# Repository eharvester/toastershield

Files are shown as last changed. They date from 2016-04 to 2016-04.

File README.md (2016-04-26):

# **toastershield**

An SMT reflow oven shield for the Arduino Uno.

## 1. Software
 
 The following steps were tested in Linux (Ubuntu).
 
### Set the following environment variables

`PATH_TO_ARDUINO_IDE = /path/to/your/arduinoIDE`

`ARDUINO_IDE_VER = 1.6.X`  (depending on your version)

`GITHUB_MIRROR = /path/to/your/github/mirror` (optional, local github mirror otherwise https://github.com is used per default)

### Connect Arduino Uno via USB cable

Make sure you have write permissions to `/dev/ttyUSB0` and execute the following commands:

`$make`

`$make upload`

If the shield is attached to the Arduino Uno board, you should hear a beep  and see something on the display.

## 2. Hardware

**_WARNING - DANGER - HIGH VOLTAGE - ELECTRIC SHOCK HAZARD - EXPERTS ONLY
(shield, heater, fan and transformer are connected to 120VAC)_**

### Parts List:

- toaster oven, to be converted (for use on 120VAC)
- Arduino Uno board
- toastershield PCB (see Eagle files and parts list)
- transformer PCB (see Eagle files and parts list)
- SH1106 OLED module
- 2 pushbuttons
- 1 LED,
- 2 wafer connectors (4 pin)
- some ribbon cable (to connect the OLED module and the switches+LED with wafer connectors)
- power cable with ground / 20 A
- power cable feedthrough coupler
- K-type thermocouple wire pair (about 50cm)
- some cable (AWG 16 for heater, AWG 24 for fan and 12VAC supply)
- 6.3mm crimp terminal spade connectors (female, insulated)
- ring tongue crimp terminals (for grounding)
- hardware for mounting boards and grounding
- fiberglass cloth (for thermal insulation)
- silicone glue

PCBs can be made with the [toner transfer method](http://www.instructables.com/id/Cheap-and-Easy-Toner-Transfer-for-PCB-Making) easily (single layer). All goes inside the oven (original buttons, switches, timers, bell aso. are stripped out). Make sure that there is sufficient air ventilation in order to keep the temperature around the boards and cables below 70C (a cooling fan might be necessary). Some thermal insulation on the outside of the oven compartment is necessary (treat fiberglass cloth with silicon glue on the cutting lines before cutting). Cut out an opening for the USB port, preferably on the front (so you can easily update the firmware and optionally monitor and control the oven from a computer).  Drill a hole into the oven compartment wall and feed the thermocouple wire pair through it and seal the hole with silicone glue later (after everything is working and tested). 

**_WARNING - DANGER - HIGH VOLTAGE - ELECTRIC SHOCK HAZARD - EXPERTS ONLY
(shield, heater, fan and transformer are connected to 120VAC)_**

## 3. To Do
- menu for adjusting temperature/time (at the moment fixed for PbSn solder) via pushbuttons
- interface for Processing
- Processing GUI  

***
## Pictures:
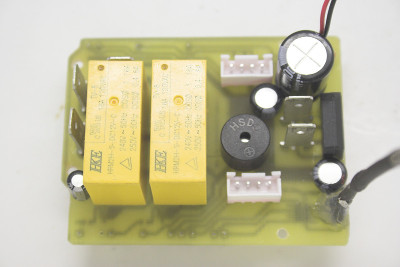
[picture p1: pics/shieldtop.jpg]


Picture 1: Assembled shield top.
***

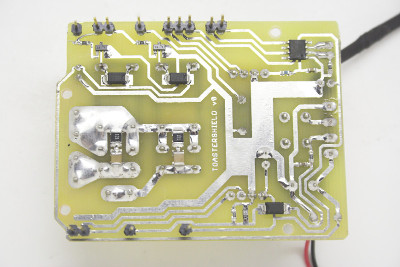
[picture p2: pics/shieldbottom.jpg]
 

Picture 2: Assembled shield bottom.
***

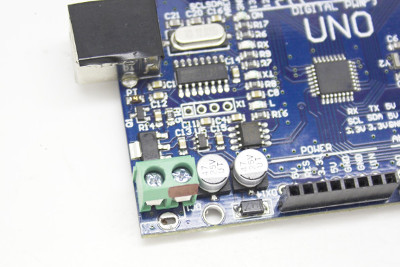
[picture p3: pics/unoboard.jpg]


Picture 3: Modified power connection, plug replaced by screw terminals.
***

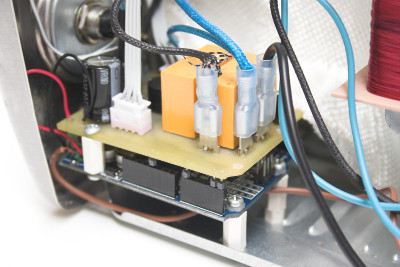
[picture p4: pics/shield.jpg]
  

Picture 4: Wired shield sitting on Uno board.
***

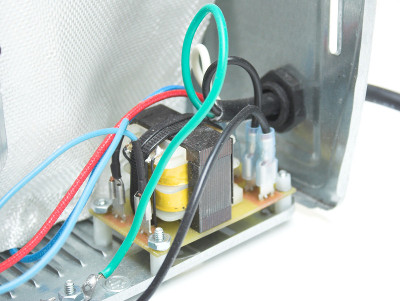
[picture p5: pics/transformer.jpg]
 

Picture 5: Wired transformer board.
***

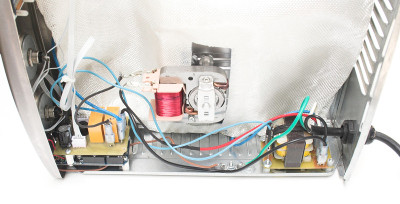
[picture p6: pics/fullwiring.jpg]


Picture 6: Complete wiring.
***
 
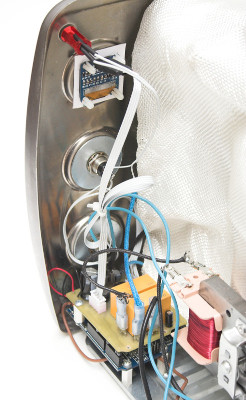
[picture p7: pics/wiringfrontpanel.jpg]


Picture 7: Wiring of front panel.
***

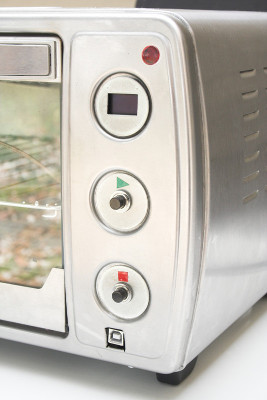
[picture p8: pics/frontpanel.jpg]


Pincture 8: Front panel.

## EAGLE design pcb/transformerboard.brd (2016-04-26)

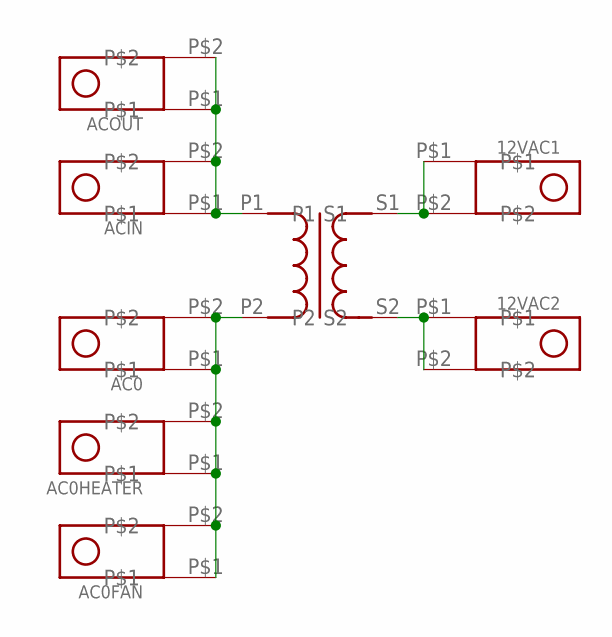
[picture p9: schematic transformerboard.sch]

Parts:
12VAC1, 12VAC2: QUICKCONNECT-TAB; QUICKCONNECT-TAB-6.35X0.81
AC0, AC0FAN, AC0HEATER: QUICKCONNECT-TAB; QUICKCONNECT-TAB-6.35X0.81
ACIN: QUICKCONNECT-TAB; QUICKCONNECT-TAB-6.35X0.81
ACOUT: QUICKCONNECT-TAB; QUICKCONNECT-TAB-6.35X0.81
T1: TRANSFORMER; 1.6X1.4.X1.3

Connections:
unnamed: ACIN.P$1, ACIN.P$2, ACOUT.P$1, ACOUT.P$2, T1.P1
unnamed: AC0.P$1, AC0.P$2, AC0FAN.P$1, AC0FAN.P$2, AC0HEATER.P$1, AC0HEATER.P$2, T1.P2
unnamed: 12VAC1.P$1, 12VAC1.P$2, T1.S1
unnamed: 12VAC2.P$1, 12VAC2.P$2, T1.S2

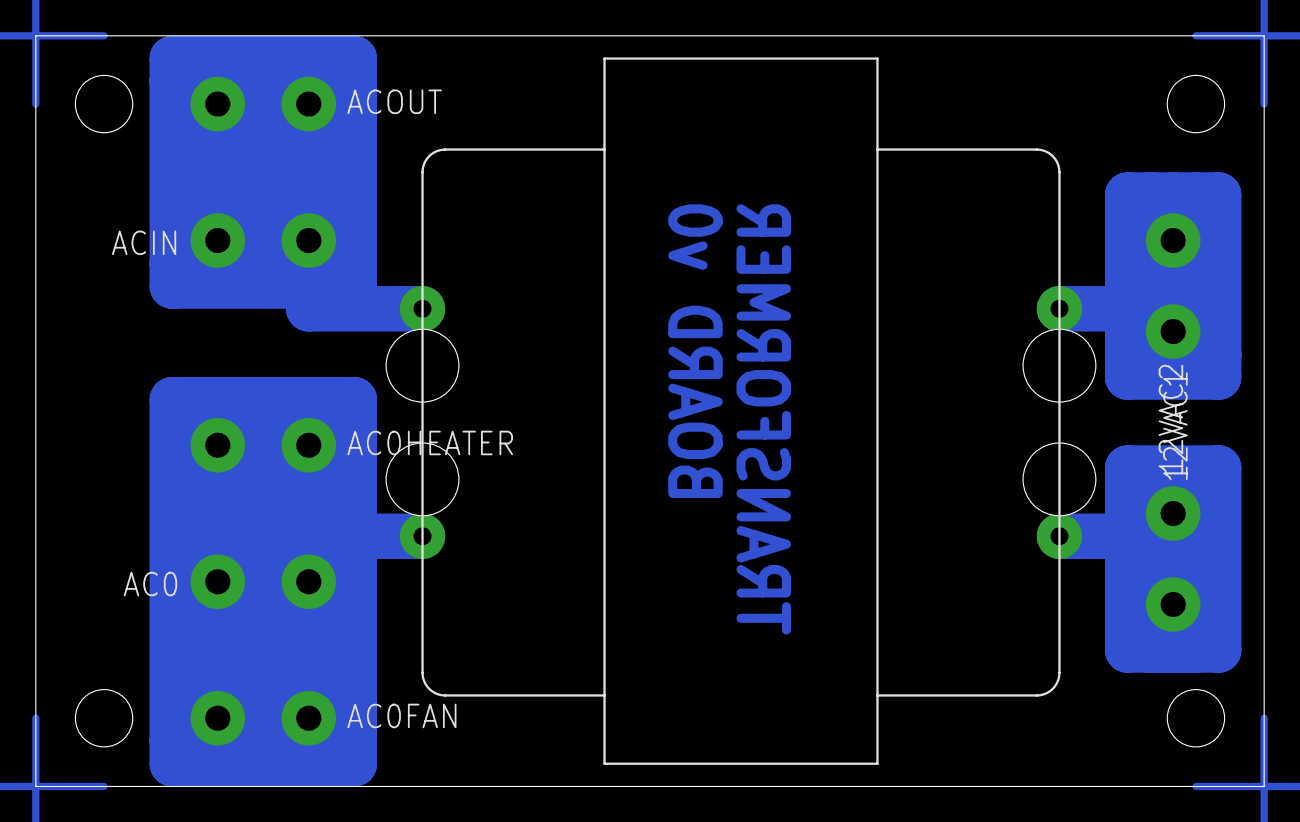
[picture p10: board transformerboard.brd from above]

Board: 2 copper layers, 68.6 x 41.9 mm, 8 parts (0 on the bottom side), 4 nets.

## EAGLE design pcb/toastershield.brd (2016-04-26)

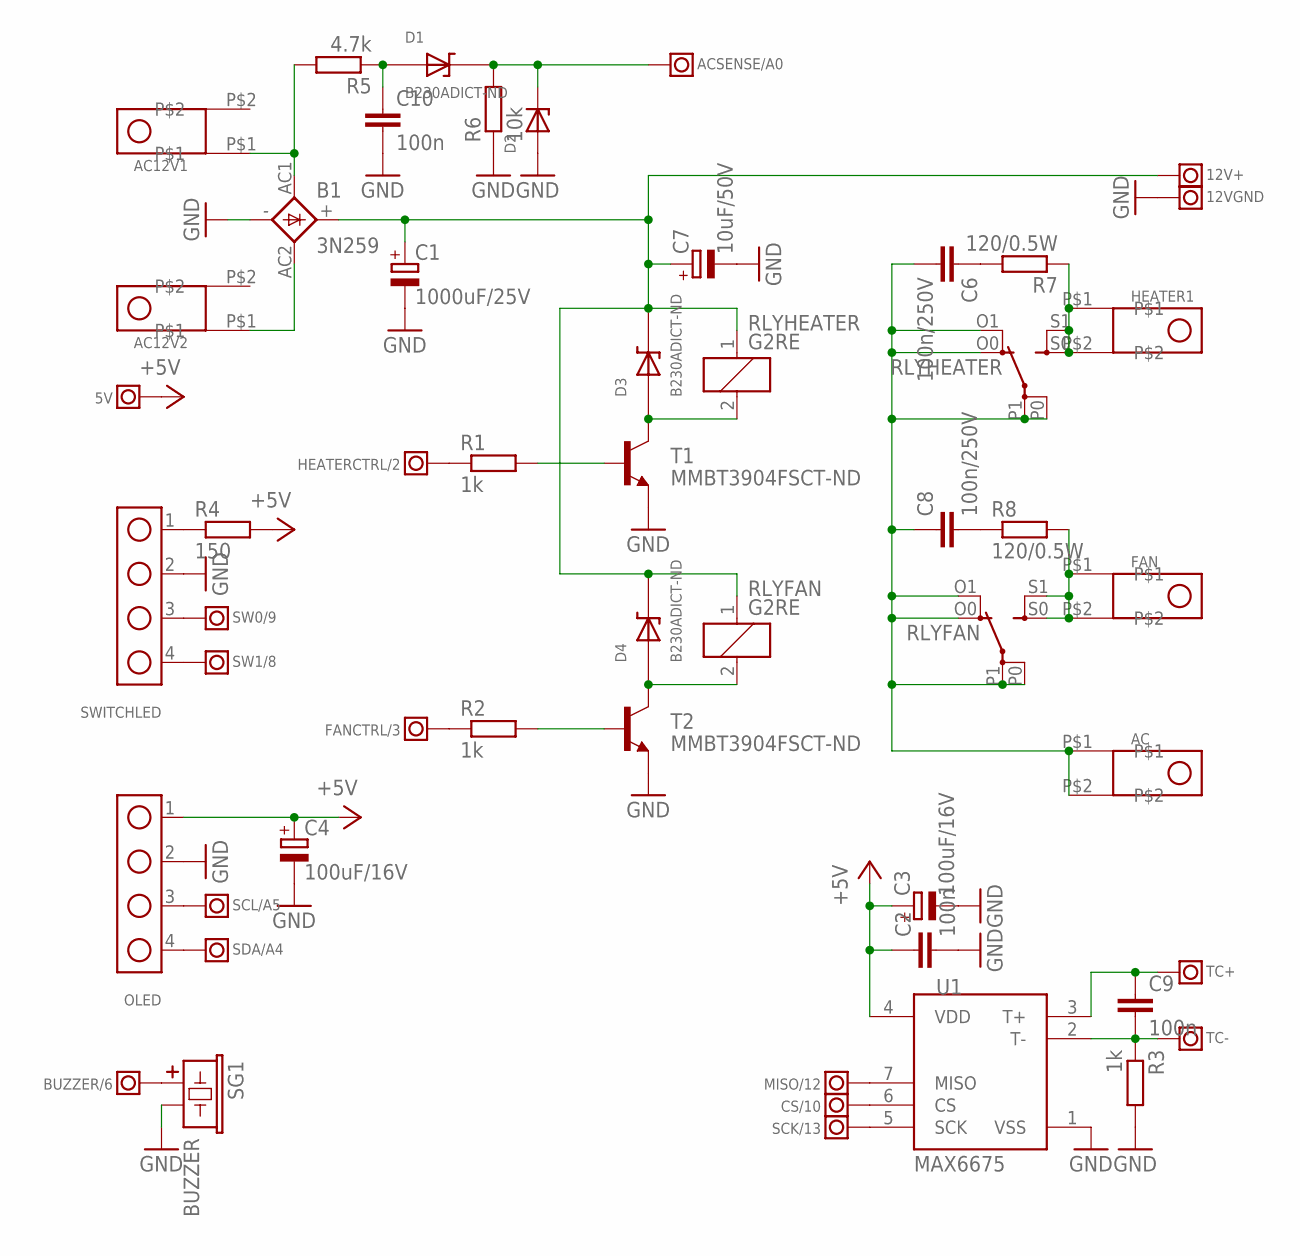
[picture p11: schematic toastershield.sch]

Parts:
5V, 12V+, 12VGND: PIN-HEADER; PIN-HEADER-MALE
AC, AC12V1, AC12V2: QUICKCONNECT-TAB; QUICKCONNECT-TAB-6.35X0.81
ACSENSE/A0: PIN-HEADER; PIN-HEADER-MALE
B1: 3N259; KBPM
BUZZER/6: PIN-HEADER; PIN-HEADER-MALE
C1: 1000uF/25V; E5-13
C2, C9, C10: 100n; C0603
C3, C4: 100uF/16V; E2,5-7
C6, C8: 100n/250V; C1210
C7: 10uF/50V; E2,5-5
CS/10: PIN-HEADER; PIN-HEADER-MALE
D1, D3, D4: B230ADICT-ND; SMA/SMB
D2: MA8051CT; SOD323-W
FAN: QUICKCONNECT-TAB; QUICKCONNECT-TAB-6.35X0.81
FANCTRL/3: PIN-HEADER; PIN-HEADER-MALE
HEATER1: QUICKCONNECT-TAB; QUICKCONNECT-TAB-6.35X0.81
HEATERCTRL/2: PIN-HEADER; PIN-HEADER-MALE
MISO/12: PIN-HEADER; PIN-HEADER-MALE
OLED: 4-PIN-WAFER-CONN; WAFER_MALE_4PIN
R1, R2, R3: 1k; R0603
R4: 150; R0603
R5: 4.7k; R0603
R6: 10k; R0603
R7, R8: 120/0.5W; R1210
RLYFAN: G2RE
RLYHEATER: G2RE
SCK/13: PIN-HEADER; PIN-HEADER-MALE
SCL/A5: PIN-HEADER; PIN-HEADER-MALE
SDA/A4: PIN-HEADER; PIN-HEADER-MALE
SG1: BUZZER; BUZZER-12X7.5
SW0/9, SW1/8: PIN-HEADER; PIN-HEADER-MALE
SWITCHLED: 4-PIN-WAFER-CONN; WAFER_MALE_4PIN
T1, T2: MMBT3904FSCT-ND; SOT-23
TC+: PIN-HEADER; PIN-HEADER-MALE
TC-: PIN-HEADER; PIN-HEADER-MALE
U1: MAX6675; SO08-MAX6675

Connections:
12VDC: 12V+.P$1, B1.+, C1.+, C7.+, D3.1 (CAT), D4.1 (CAT), RLYFAN.1, RLYHEATER.1
+5V: 5V.P$1, C2.1, C3.+, C4.+, OLED.1, R4.2, U1.4 (VDD)
AC: AC.P$1, AC.P$2, C6.2, C8.1, RLYFAN.O0 (O), RLYFAN.O1 (O), RLYFAN.P0, RLYFAN.P1, RLYHEATER.O0 (O), RLYHEATER.O1 (O), RLYHEATER.P0, RLYHEATER.P1
AC12V0: AC12V1.P$1, B1.AC1, R5.2
AC12V1: AC12V2.P$1, B1.AC2
BUZZER: BUZZER/6.P$1, SG1.+ (1)
FAN: FAN.P$1, FAN.P$2, R8.2, RLYFAN.S0 (S), RLYFAN.S1 (S)
GND: 12VGND.P$1, B1.-, C1.-, C2.2, C3.-, C4.-, C7.-, C10.2, D2.A (AN), OLED.2, R3.2, R6.1, SG1.- (2), SWITCHLED.2, T1.2 (E), T2.2 (E), U1.1 (VSS)
HEATER: HEATER1.P$1, HEATER1.P$2, R7.1, RLYHEATER.S0 (S), RLYHEATER.S1 (S)
LED+: R4.1, SWITCHLED.1
unnamed: C9.1, TC+.P$1, U1.3 (T+)
unnamed: FANCTRL/3.P$1, R2.1
unnamed: HEATERCTRL/2.P$1, R1.1
unnamed: D3.2 (AN), RLYHEATER.2, T1.3 (C)
unnamed: D4.2 (AN), RLYFAN.2, T2.3 (C)
unnamed: R1.2, T1.1 (B)
unnamed: R2.2, T2.1 (B)
unnamed: MISO/12.P$1, U1.7 (MISO)
unnamed: C9.2, R3.1, TC-.P$1, U1.2 (T-)
unnamed: CS/10.P$1, U1.6 (CS)
unnamed: SCK/13.P$1, U1.5 (SCK)
unnamed: SW0/9.P$1, SWITCHLED.3
unnamed: SW1/8.P$1, SWITCHLED.4
unnamed: OLED.3, SCL/A5.P$1
unnamed: OLED.4, SDA/A4.P$1
unnamed: C10.1, D1.2 (AN), R5.1
unnamed: ACSENSE/A0.P$1, D1.1 (CAT), D2.C (CAT), R6.2
unnamed: C8.2, R8.1
unnamed: C6.1, R7.2

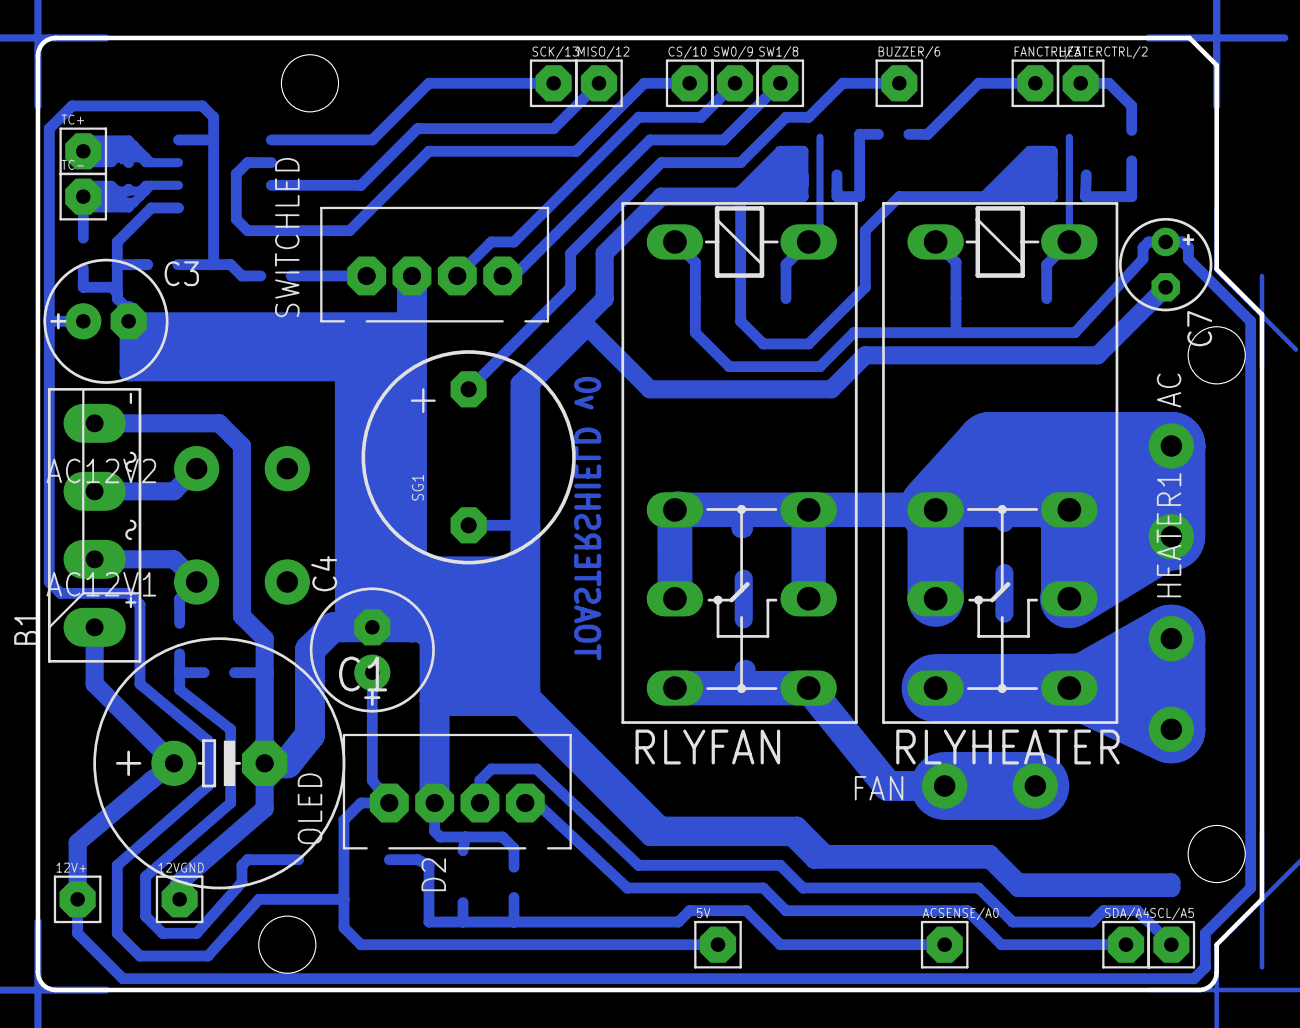
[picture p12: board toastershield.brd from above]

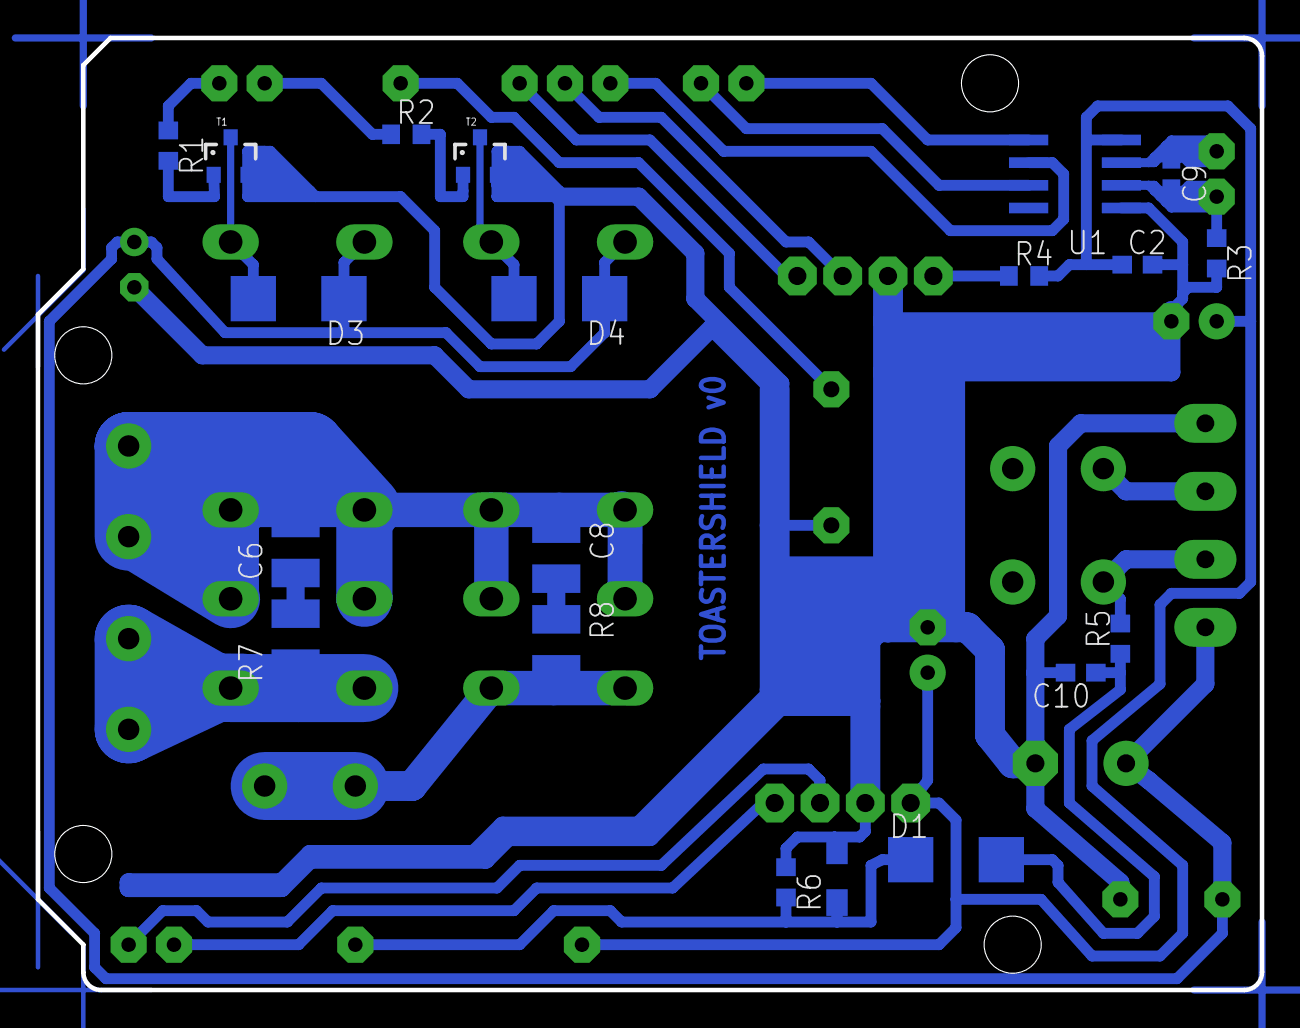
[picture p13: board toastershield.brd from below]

Board: 2 copper layers, 68.6 x 53.3 mm, 51 parts (19 on the bottom side), 29 nets.

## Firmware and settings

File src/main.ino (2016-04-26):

// Toastershield
// a shield for Arduino Uno
// to use a toaster oven as SDM reflow oven

#define Version 0.1

// pin definitions
#define SW0 9
#define SW1 8

#define FANCTRL 3
#define HEATERCTRL 2

#define ACSENSE A0

//MAX6675 SPI pin definitions
#define CSTC  10               //chip select pin for MAX6675

#define SWSTART SW0
#define SWSTOP SW1


// PID controller definitions
#include <PID_v1.h>
double Setpoint, Input, Output;
#include "PIDparams.h"

// PID controller object
PID myPID(&Input, &Output, &Setpoint, Kp, Ki, Kd, DIRECT);

unsigned long windowStartTime;

#define PWM_WINDOWSIZE_MS 5000
#define PID_OUTPUT_MAX 800.0
#define PID_OUTPUT_MIN 0.0

// Thermocouple definitions
#include <xMAX6675.h>      

#define MOSI  11    //master out slave in (not connected, only read MAX6675)
#define MISO  12    //master in slave out
#define SCK   13    //serial clock

// thermocouple object
xMAX6675 tc; 

#define tCONV 220   // conversion time is 0.22s per data sheet
#define nMEAS 8     // number of measurements to average

double TempC[nMEAS], TempCAvg;

unsigned char TempCIdx;
unsigned long TempLastMillis;

unsigned long SoakStart, HeatStart;

#include "reflowdefs.h"

#define HEATRAMP_TIMEOUT 200000UL
#define HEATSOAK_TIMEOUT HEATRAMP_TIMEOUT+200000UL
#define HEATREFLOW_TIMEOUT HEATSOAK_TIMEOUT+200000UL

// LCD definitions
#include <Arduino.h>
#include <Wire.h>
#include <MicroLCD.h>
LCD_SSD1306 lcd; /* for SH1106 OLED module */

#define LCD_SIZEX SSD1306_LCDWIDTH
#define LCD_SIZEY SSD1306_LCDHEIGHT

#include "lcdsymbols.h"

#define READY_TEXT    "  READY   "
#define RAMPUP_TEXT   " HEAT UP  "
#define SOAK_TEXT     "   SOAK   "      
#define REFLOWUP_TEXT "  REFLOW  "
#define OPENDOOR_TEXT "OPEN DOOR!"
#define COOLDOWN_TEXT "COOL DOWN "
#define ERROR_TEXT    "  ERROR   "

#define LCD_YPOS_TEMP 1
#define LCD_YPOS_SYMBOL 1
#define LCD_YPOS_BAR 4
#define LCD_YPOS_STATE 6

// Buzzer
#include "pitches.h"
#define BUZZER 6 // pin

#define TL 50
#define PAUSE 250

// delay for relays to turn them on/off tuned for AC zero crossing 
// these values should be good for the relay model
// they can be optimizied through characterization
// for other models they must be changed through characterization
//  or simpe AC oscilloscope measurement of switched voltage
#define HEATERON_DELAY 9
#define HEATEROFF_DELAY 5
#define FANRON_DELAY 9
#define FANOFF_DELAY 3

#define ACSENSETIMEOUT_MS 17 // avoid blocking, when oven is not powered by AC, but USB

unsigned char AcSense(void) {

 unsigned long Millis;

 Millis = millis();
 while (digitalRead(ACSENSE)) {if (millis() > Millis+ACSENSETIMEOUT_MS) return 0;};

 Millis = millis();
 while (!digitalRead(ACSENSE)) {if (millis() > Millis+ACSENSETIMEOUT_MS) return 0;};

 return 1;
}

#define HEATER_ON {if (AcSense()) { delay(HEATERON_DELAY); digitalWrite(HEATERCTRL,1);} lcd.setCursor(8,LCD_YPOS_SYMBOL); lcd.draw(HeaterSymbol16x16,16,16);} 
#define HEATER_OFF {if (AcSense()) { delay(HEATEROFF_DELAY); digitalWrite(HEATERCTRL,0);} lcd.setCursor(8,LCD_YPOS_SYMBOL); lcd.draw(EmptySymbol16x16,16,16);}

#define IF_HEATER_ON digitalRead(HEATERCTRL)

#define FAN_ON {if (AcSense()) {  delay(FANRON_DELAY); digitalWrite(FANCTRL,1);} lcd.setCursor(104,LCD_YPOS_SYMBOL); lcd.draw(FanSymbol16x16,16,16);} 
#define FAN_OFF  {if (AcSense()) { delay(FANOFF_DELAY); digitalWrite(FANCTRL,0);} lcd.setCursor(104,LCD_YPOS_SYMBOL); lcd.draw(EmptySymbol16x16,16,16);}

#define IF_FAN_ON digitalRead(FANCTRL)

enum ReflowFsmState {READY, STARTPID, RAMPUP, SOAK, REFLOWUP, OPENDOOR, COOLDOWN, ERROR} ReflowFsm;

void alarm() {
 tone(BUZZER, NOTE_B7);
 delay(TL);
 tone(BUZZER, NOTE_D7);
 delay(TL);
 tone(BUZZER, NOTE_F7);
 delay(TL);
 tone(BUZZER, NOTE_D7);
 delay(TL);
 tone(BUZZER, NOTE_B7);
 delay(TL);
   
 noTone(BUZZER);
}

void beep () {
 tone(BUZZER, NOTE_B7);
 delay(TL);
 noTone(BUZZER);
}

void errorbeep () {
 tone(BUZZER, NOTE_F7);
 delay(TL);
 noTone(BUZZER);
}

bool pressed(unsigned char pbswitch) {

 if (!digitalRead(pbswitch)) {
   beep();
   while (!digitalRead(pbswitch));
   return true;
 } else {
   return false;
 }
}

void wrongpressed(unsigned char pbswitch) {

 unsigned int vandalcheck = 0; 

 if (!digitalRead(pbswitch)) {
  errorbeep();
  for (;(vandalcheck < 10000) && !digitalRead(pbswitch); vandalcheck++);
 }

}

// average function
double Avg (double Vals[]) {

 unsigned char n;
 double Sum = 0.0;
// sum values   
 for (n = 0; n < nMEAS; n++) Sum += Vals[n];
 return (Sum/(double)nMEAS);
}

#define IF_STOP {if (pressed(SWSTOP)) ReflowFsm = COOLDOWN;}
#define WRONG_STOP {wrongpressed(SWSTOP); }
#define WRONG_START {wrongpressed(SWSTART); }

void setup() {

 unsigned char n;
 unsigned long Millis;

 Millis = millis();
  
 tc.attach(MOSI,MISO,SCK,CSTC); // attach the thermocouple

// switches pull up
 pinMode(SW0, INPUT_PULLUP);  
 pinMode(SW1, INPUT_PULLUP);  

 pinMode(ACSENSE,INPUT);

// relays
 digitalWrite(FANCTRL,0);
 pinMode(FANCTRL,OUTPUT);

 digitalWrite(HEATERCTRL,0);
 pinMode(HEATERCTRL,OUTPUT);

// buzzer
 pinMode(BUZZER,OUTPUT);

 delay(100);  // otherwise OLED does not start
// LCD
 lcd.begin();
 lcd.clear();
 lcd.setCursor(40, 3);
 lcd.setFontSize(FONT_SIZE_XLARGE);
 lcd.print("V "); lcd.print(Version);
 delay(1000);
 lcd.clear();
 lcd.setCursor(0,0);
 lcd.draw(logo, 128, 64);
 errorbeep();
 delay(100);
 beep();
 delay(500);


// PID controller
 Setpoint = PID_OUTPUT_MIN;
 Output = 0.0; 
 Input = 0.0;
 windowStartTime = Millis;

//tell the PID to range between 0 and the full window size
 myPID.SetOutputLimits(PID_OUTPUT_MIN, PID_OUTPUT_MAX);

//we do not turn on the PID for now
 myPID.SetMode(MANUAL);

 for (n = 0; n < nMEAS;n++) {
  delay(tCONV);
  TempC[n] = tc.readC();
 }
 TempCAvg = Avg(TempC);
 TempCIdx = 0;

 TempLastMillis = Millis;

 ReflowFsm = READY;
  
 lcd.clear();
}

void loop() {

 unsigned long Millis;
 unsigned char CursorX;

 Millis = millis();

// LCD display output
 lcd.setCursor(24,LCD_YPOS_STATE); //position for state
// FSM output decoder  for display
 switch (ReflowFsm) {
  case READY:
   lcd.print(F(READY_TEXT));
   lcd.setCursor((EMPTYBAR_SIZEX-LCD_SIZEX)/2,LCD_YPOS_BAR); lcd.draw(emptybar,EMPTYBAR_SIZEX,EMPTYBAR_SIZEY);
   break;
  case STARTPID:
  case RAMPUP:
   lcd.print(F(RAMPUP_TEXT));
   break;
  case SOAK:
   lcd.print(F(SOAK_TEXT));   
   CursorX = (unsigned char)((double)(Millis - SoakStart)/(double)SoakTime*double(EMPTYBAR_SIZEX/FULLBARSTEP_SIZEX))*FULLBARSTEP_SIZEX;
   if (CursorX >= FULLBARSTEP_SIZEX) { lcd.setCursor(CursorX-FULLBARSTEP_SIZEX,LCD_YPOS_BAR);lcd.draw(fullbarstep,FULLBARSTEP_SIZEX,FULLBARSTEP_SIZEY);}
   break;
  case REFLOWUP:
   lcd.print(F(REFLOWUP_TEXT));
   lcd.setCursor(0,LCD_YPOS_BAR); lcd.draw(emptybar,EMPTYBAR_SIZEX,EMPTYBAR_SIZEY);
   break;
  case OPENDOOR:
   lcd.print(F(OPENDOOR_TEXT));
   break;
  case COOLDOWN:
   lcd.print(F(COOLDOWN_TEXT));
   lcd.setCursor(0,LCD_YPOS_BAR); lcd.draw(emptybar,EMPTYBAR_SIZEX,EMPTYBAR_SIZEY);
   break;
  case ERROR:
   lcd.print(F(ERROR_TEXT));
   break;
 }




 if (Millis > TempLastMillis+tCONV) {  // read only if at least tCONV ha elapsed
// read temperature
  TempC[TempCIdx] = tc.readC();
  if (TempCIdx == (nMEAS-1)) TempCIdx = 0; else TempCIdx++;
// calculate new average
  TempCAvg = Avg(TempC);
// save last time stamp
  TempLastMillis = Millis;
  lcd.setCursor(44,LCD_YPOS_TEMP); lcd.print(TempCAvg,0); lcd.print(" C "); 
}  
 

 Input = TempCAvg;  // Temp value for PID controller

// FSM output decoder  
 switch (ReflowFsm) {
  case READY:
   WRONG_STOP;
   FAN_OFF; 
   HEATER_OFF;
   break;
  case STARTPID:
   Setpoint = PreheatTemp;    
   Output = 0.0; // this value needs to be reset before PID is turned on
   myPID.SetMode(AUTOMATIC); // turn on the PID, initializes controller
   windowStartTime = Millis; // initialize PWM element
   HeatStart = Millis; // log time when heat is applied for error condition
   break;
  case RAMPUP:
  case SOAK:
   WRONG_START;
   FAN_ON;
   myPID.Compute();
   if ((Millis - windowStartTime) >= (unsigned long) PWM_WINDOWSIZE_MS) { //time to shift the Relay Window
    windowStartTime += PWM_WINDOWSIZE_MS;
   }
   if ((unsigned long)(Output/PID_OUTPUT_MAX*(double)PWM_WINDOWSIZE_MS) > (Millis - windowStartTime)) { 
    HEATER_ON;
   } else {
    HEATER_OFF;
   }
   break;
  case REFLOWUP:
   WRONG_START;
   myPID.SetMode(MANUAL); // turn PID off
   FAN_ON;
   HEATER_ON;
  break;
  case OPENDOOR:
   Setpoint = PID_OUTPUT_MIN;
   FAN_ON;
   HEATER_OFF;
   alarm();
   break;
  case COOLDOWN:
   WRONG_START;
   WRONG_STOP;
   Setpoint = PID_OUTPUT_MIN;
   myPID.SetMode(MANUAL); // turn PID off
   FAN_ON;
   HEATER_OFF;
   break;
  case ERROR:
   WRONG_START;
   WRONG_STOP;
   FAN_ON;
   HEATER_OFF;
   errorbeep(); delay (500);
   break;
 }


// FSM condition, next state  
 switch (ReflowFsm) {
  case READY:
   if (TempCAvg > ReadyTemp) ReflowFsm = COOLDOWN; 
   else if (pressed(SWSTART)) ReflowFsm = STARTPID;
   break;
  case STARTPID:
   ReflowFsm = RAMPUP;
   break;
  case RAMPUP:
   IF_STOP;
   SoakStart = Millis; // save start time
   if (TempCAvg >= SoakTemp) ReflowFsm = SOAK;
   if (Millis-HeatStart >= HEATRAMP_TIMEOUT) ReflowFsm = ERROR; 
   break;
  case SOAK: 
   IF_STOP;
   if (pressed(SWSTOP)) ReflowFsm = COOLDOWN;
   if ((Millis - SoakStart) >= SoakTime) ReflowFsm = REFLOWUP;
   if (Millis-HeatStart >= HEATSOAK_TIMEOUT) ReflowFsm = ERROR;
   break;
  case REFLOWUP:
   IF_STOP;
   if (TempCAvg >= ReflowTempMax) ReflowFsm = OPENDOOR; 
   if (Millis-HeatStart >= HEATREFLOW_TIMEOUT) ReflowFsm = ERROR;
   break;
  case OPENDOOR:
   if (pressed(SWSTART) || pressed(SWSTOP)) ReflowFsm = COOLDOWN;
   break;
  case COOLDOWN:
   if (TempCAvg < ReadyTemp-FanHysteresis) ReflowFsm = READY;
   break;   
  case ERROR:
   break;
 }

}

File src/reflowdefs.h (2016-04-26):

// SMD Reflow Definitions
// change the SMD reflow parameters here
//
/*
                     ReflowTempMax  -
                                   / \
                                  /   \
                                 /     \
                                /       \
 PreheatTemp -------------------         \ 
 SoakTemp  -/-                 :          \
           /:                  :           \
          / :                  :            \
        -/- :                  :            -\---ReadyTemp
        /   :                  :              \
       /    :                  :               \
 ------     :                  :                ---
            |<--- SoakTime --->|              
*/
// values for 35-65 Sn-Pb solder 
double PreheatTemp = 150.0;  // temp in C 
double SoakTemp = 140.0; // temp in C, when soak time starts
unsigned long SoakTime = 90000; // soak time in ms
double ReflowTempMax = 205.0; // maximum temp, swings over quickly!
double ReadyTemp = 50.0;  // temp in C, when oven becomes ready for next cycle 
double FanHysteresis = 2.0; // temp in C, fan is turned on/off at ReadyTemp

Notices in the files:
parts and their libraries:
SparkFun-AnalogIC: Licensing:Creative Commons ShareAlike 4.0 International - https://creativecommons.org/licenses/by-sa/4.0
